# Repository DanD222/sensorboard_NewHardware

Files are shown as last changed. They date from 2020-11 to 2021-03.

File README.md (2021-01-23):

# sensorboard_NewHardware
Hardware for a new version of the OpenVario Sensorboard, stemming from discussion in these issues:

https://github.com/Openvario/sensord/issues/23

https://github.com/Openvario/sensord/issues/26

Features / comparison to the original OpenVario sensorboard:

   - Updated sensors and voltage regulators
   - A USB connector has been added in place of the 6pin I2C connector
   - There are footprints for three differential sensors (DLHR-L30G-E1BD-C-NAV8, 4515DO-DS3BK030DPL, AMS5915)
   - There are two I2C buses:
       - 1 - SDA0/SCL0 is the on-board sensor I2C bus, this goes to the ESP32
       - 2 - SDA1/SCL0 is the external I2C bus, going from the ESP32 to the 10pin IDC connector
       
     Both buses can be linked via solder jumpers on the bottom layer - this allows the sensors to be connected to the IDC connector directly without using the ESP32. This can be useful to get the new sensorboard integrated into the current OpenVario setup without having to implement the ESP32 first.
   - Pins for UART0 and UART1. The UART0 pin header has a 5V pin, so that it can connect for example directly to a HC-05 Bluetooth module (or a board with an RS232 interface)
   - An on-board 12V->5V PSU so that the sensorboard can be used stand-alone
   - Additional filtering - 5VD powers the digital stuff (USB, ESP32 voltage regulator); 5VC powers the sensitive stuff (sensor voltage regulators, audio amp)
   - The audio amp is a class AB TPA6211A1DRBR
   - There are pins around the audio amp so that a daughter board can be used in order to experiment with different amps
   - There are pins for selecting the source to the audio amp. This can be either the ESP32 for future use, or external input (to be backwards-compatible)
   - The OAT sensor has been moved to a 2.5mm jack
   - The audio output is on a 3.5mm stereo jack

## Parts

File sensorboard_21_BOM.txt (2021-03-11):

Partlist exported from /Users/dan/openvario/hpmax/sensorboard_21.sch at 8/3/21 23:23 PM

Part                  Value                          Device                            Package                        Description                                                                                                                                           4515DO-DS3BK030DPL_NO_SILK AMS-5915 ARROW_ELECTRONICS-PURCHASE-URL                              AVAILABILITY DESCRIPTION                                                                                                                   DIGIKEY-PURCHASE-URL                              DLHR-L30G-E1BD-C-NAV8 HEIGHT  MANUFACTURER_NAME         MANUFACTURER_PART_NUMBER        MF                 MOUSER-PURCHASE-URL                              MOUSER_PART_NUMBER   MOUSER_PRICE-STOCK                                                                                                             MP               MPN        OC_FARNELL OC_NEWARK PACKAGE                     POPULARITY PRICE PURCHASE-URL                                                  SPICEPREFIX
12V_IN                22-23-2021                     22-23-2021                        22-23-2021                     .100" (2.54mm) Center Header - 2 Pin                                                                                                                                                                                                                                                                                                                                                                                                                                                                                                       MOLEX                                                                                                                                                                                                                                    22-23-2021 1462926    25C3832                               40                                                                                        
AUD_DAUGHTER-B_OUT                                   PINHD-1X2                         1X02                           PIN HEADER                                                                                                                                                                                                                                                                                                                                                                                                                                                                                                                                                                                                                                                                                                                                                                                                                                      98                                                                                        
AUD_IN                                               PINHD-1X3                         1X03                           PIN HEADER                                                                                                                                                                                                                                                                                                                                                                                                                                                                                                                                                                                                                                                                                                                                                                                                                                      92                                                                                        
C1                    100nF                          C-EUC0603                         C0603                          CAPACITOR, European symbol                                                                                                                                                                                                                                                                                                                                                                                                                                                                                                                                                                                                                                                                                                                                                                                                                      73                                                                             C          
C2                    100nF                          C-EUC0603                         C0603                          CAPACITOR, European symbol                                                                                                                                                                                                                                                                                                                                                                                                                                                                                                                                                                                                                                                                                                                                                                                                                      73                                                                             C          
C3                    100nF                          C-EUC0805                         C0805                          CAPACITOR, European symbol                                                                                                                                                                                                                                                                                                                                                                                                                                                                                                                                                                                                                                                                                                                                                                                                                      88                                                                             C          
C4                    10uF                           C-EUC0805                         C0805                          CAPACITOR, European symbol                                                                                                                                                                                                                                                                                                                                                                                                                                                                                                                                                                                                                                                                                                                                                                                                                      88                                                                             C          
C5                    10uF                           C-EUC0805                         C0805                          CAPACITOR, European symbol                                                                                                                                                                                                                                                                                                                                                                                                                                                                                                                                                                                                                                                                                                                                                                                                                      88                                                                             C          
C6                    1uF                            C-EUC0805                         C0805                          CAPACITOR, European symbol                                                                                                                                                                                                                                                                                                                                                                                                                                                                                                                                                                                                                                                                                                                                                                                                                      88                                                                             C          
C7                    1uF                            C-EUC0805                         C0805                          CAPACITOR, European symbol                                                                                                                                                                                                                                                                                                                                                                                                                                                                                                                                                                                                                                                                                                                                                                                                                      88                                                                             C          
C8                    10uF                           C-EUC0805                         C0805                          CAPACITOR, European symbol                                                                                                                                                                                                                                                                                                                                                                                                                                                                                                                                                                                                                                                                                                                                                                                                                      88                                                                             C          
C9                    1uF                            C-EUC0805                         C0805                          CAPACITOR, European symbol                                                                                                                                                                                                                                                                                                                                                                                                                                                                                                                                                                                                                                                                                                                                                                                                                      88                                                                             C          
C10                   10uF                           C-EUC0805                         C0805                          CAPACITOR, European symbol                                                                                                                                                                                                                                                                                                                                                                                                                                                                                                                                                                                                                                                                                                                                                                                                                      88                                                                             C          
C11                   100nF                          C-EUC0805                         C0805                          CAPACITOR, European symbol                                                                                                                                                                                                                                                                                                                                                                                                                                                                                                                                                                                                                                                                                                                                                                                                                      88                                                                             C          
C12                   10uF                           C-EUC0805                         C0805                          CAPACITOR, European symbol                                                                                                                                                                                                                                                                                                                                                                                                                                                                                                                                                                                                                                                                                                                                                                                                                      88                                                                             C          
C13                   100nF                          C-EUC0805                         C0805                          CAPACITOR, European symbol                                                                                                                                                                                                                                                                                                                                                                                                                                                                                                                                                                                                                                                                                                                                                                                                                      88                                                                             C          
C14                   1uF                            C-EUC0805                         C0805                          CAPACITOR, European symbol                                                                                                                                                                                                                                                                                                                                                                                                                                                                                                                                                                                                                                                                                                                                                                                                                      88                                                                             C          
C15                   1uF                            C-EUC0805                         C0805                          CAPACITOR, European symbol                                                                                                                                                                                                                                                                                                                                                                                                                                                                                                                                                                                                                                                                                                                                                                                                                      88                                                                             C          
C16                   100nF                          C-EUC0805                         C0805                          CAPACITOR, European symbol                                                                                                                                                                                                                                                                                                                                                                                                                                                                                                                                                                                                                                                                                                                                                                                                                      88                                                                             C          
C17                   22uF/25V                       CL31A226KAHNNNE                   CAPC3216X180N                  SAMSUNG ELECTRO-MECHANICS - CL31A226KAHNNNE - CAP, 22UF, 25V, MLCC, 1206                                                                                                                                                                                           SAMSUNG ELECTRO-MECHANICS - CL31A226KAHNNNE - CAP, 22UF, 25V, MLCC, 1206                                                                                                                              1.8mm   Samsung Electro-Mechanics CL31A226KAHNNNE                                                                                     N/A                  https://www.mouser.com/Search/Refine.aspx?Keyword=N%2FA                                                                                                                                                                                                                                               
C18                   22uF/25V                       CL31A226KAHNNNE                   CAPC3216X180N                  SAMSUNG ELECTRO-MECHANICS - CL31A226KAHNNNE - CAP, 22UF, 25V, MLCC, 1206                                                                                                                                                                                           SAMSUNG ELECTRO-MECHANICS - CL31A226KAHNNNE - CAP, 22UF, 25V, MLCC, 1206                                                                                                                              1.8mm   Samsung Electro-Mechanics CL31A226KAHNNNE                                                                                     N/A                  https://www.mouser.com/Search/Refine.aspx?Keyword=N%2FA                                                                                                                                                                                                                                               
C19                   1uF                            C-EUC0805                         C0805                          CAPACITOR, European symbol                                                                                                                                                                                                                                                                                                                                                                                                                                                                                                                                                                                                                                                                                                                                                                                                                      88                                                                             C          
C20                   47pF                           C-EUC0805                         C0805                          CAPACITOR, European symbol                                                                                                                                                                                                                                                                                                                                                                                                                                                                                                                                                                                                                                                                                                                                                                                                                      88                                                                             C          
C21                   22uF/25V                       CL31A226KAHNNNE                   CAPC3216X180N                  SAMSUNG ELECTRO-MECHANICS - CL31A226KAHNNNE - CAP, 22UF, 25V, MLCC, 1206                                                                                                                                                                                           SAMSUNG ELECTRO-MECHANICS - CL31A226KAHNNNE - CAP, 22UF, 25V, MLCC, 1206                                                                                                                              1.8mm   Samsung Electro-Mechanics CL31A226KAHNNNE                                                                                     N/A                  https://www.mouser.com/Search/Refine.aspx?Keyword=N%2FA                                                                                                                                                                                                                                               
C22                   22uF/25V                       CL31A226KAHNNNE                   CAPC3216X180N                  SAMSUNG ELECTRO-MECHANICS - CL31A226KAHNNNE - CAP, 22UF, 25V, MLCC, 1206                                                                                                                                                                                           SAMSUNG ELECTRO-MECHANICS - CL31A226KAHNNNE - CAP, 22UF, 25V, MLCC, 1206                                                                                                                              1.8mm   Samsung Electro-Mechanics CL31A226KAHNNNE                                                                                     N/A                  https://www.mouser.com/Search/Refine.aspx?Keyword=N%2FA                                                                                                                                                                                                                                               
C23                   470pF                          C-EUC0805                         C0805                          CAPACITOR, European symbol                                                                                                                                                                                                                                                                                                                                                                                                                                                                                                                                                                                                                                                                                                                                                                                                                      88                                                                             C          
C24                   470pF                          C-EUC0805                         C0805                          CAPACITOR, European symbol                                                                                                                                                                                                                                                                                                                                                                                                                                                                                                                                                                                                                                                                                                                                                                                                                      88                                                                             C          
C25                   220nF                          C-EUC1206                         C1206                          CAPACITOR, European symbol                                                                                                                                                                                                                                                                                                                                                                                                                                                                                                                                                                                                                                                                                                                                                                                                                      54                                                                             C
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

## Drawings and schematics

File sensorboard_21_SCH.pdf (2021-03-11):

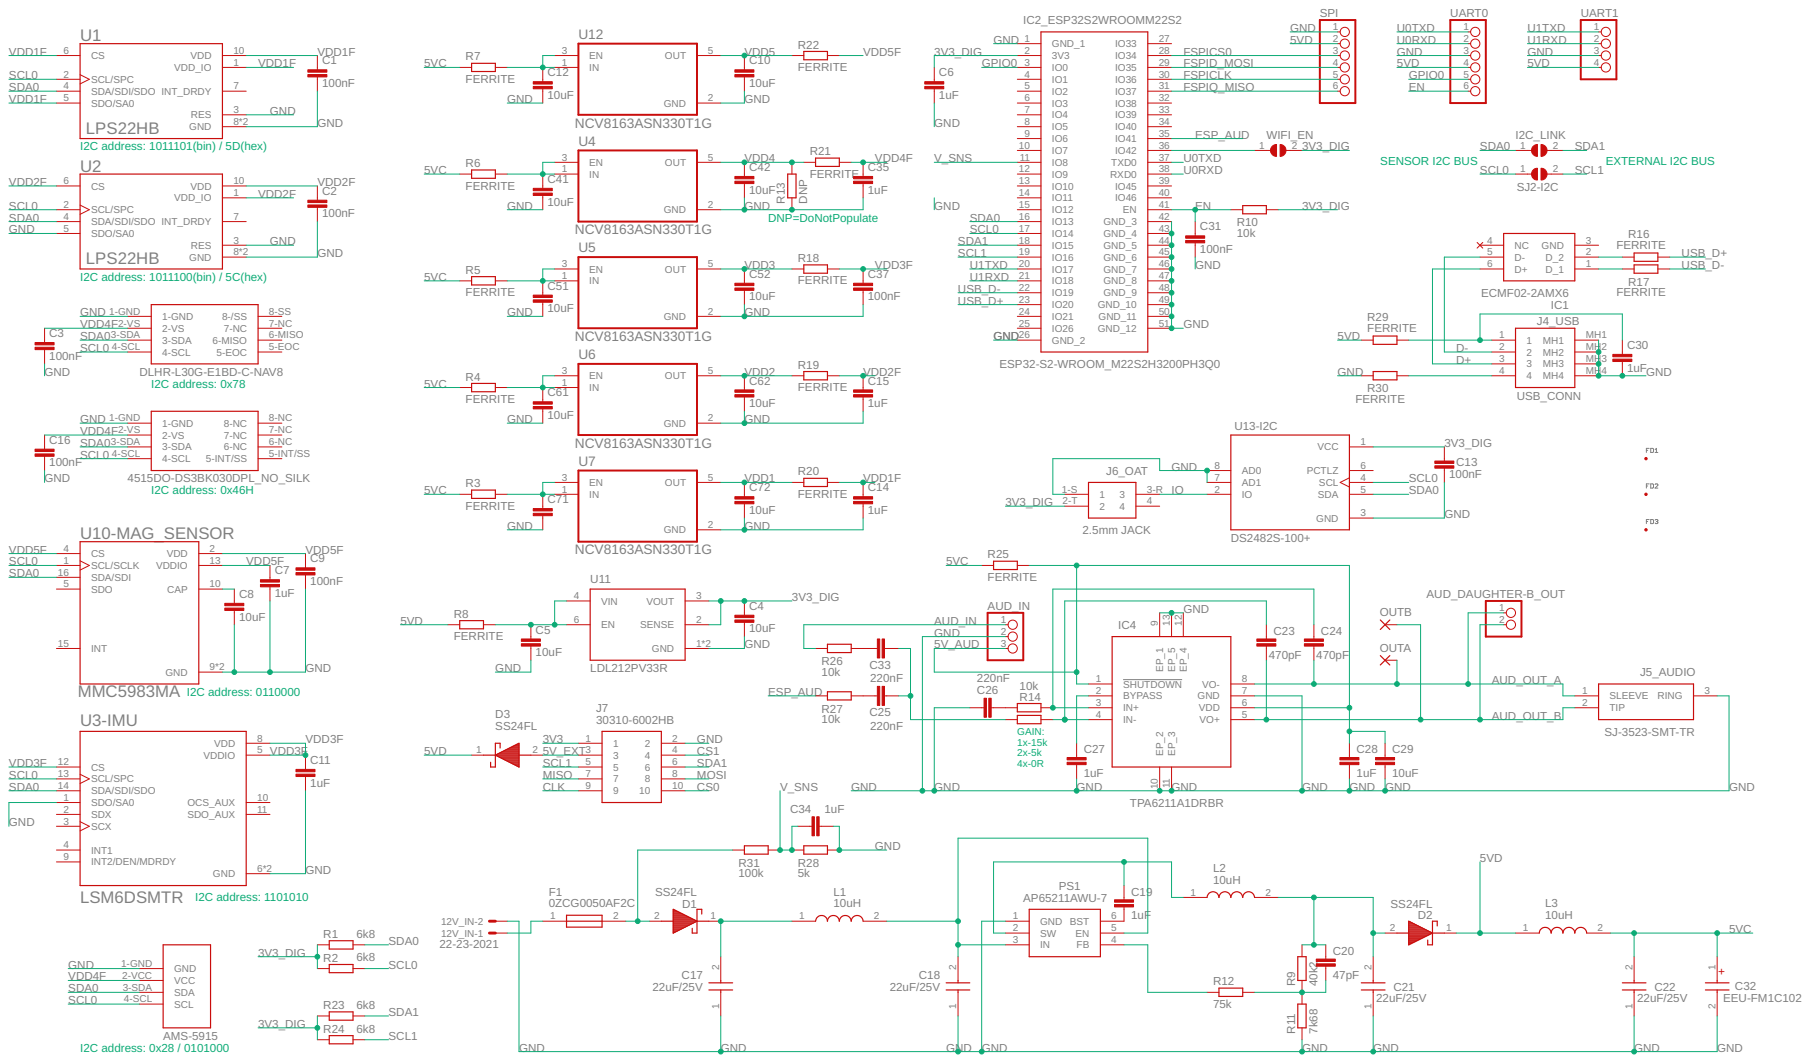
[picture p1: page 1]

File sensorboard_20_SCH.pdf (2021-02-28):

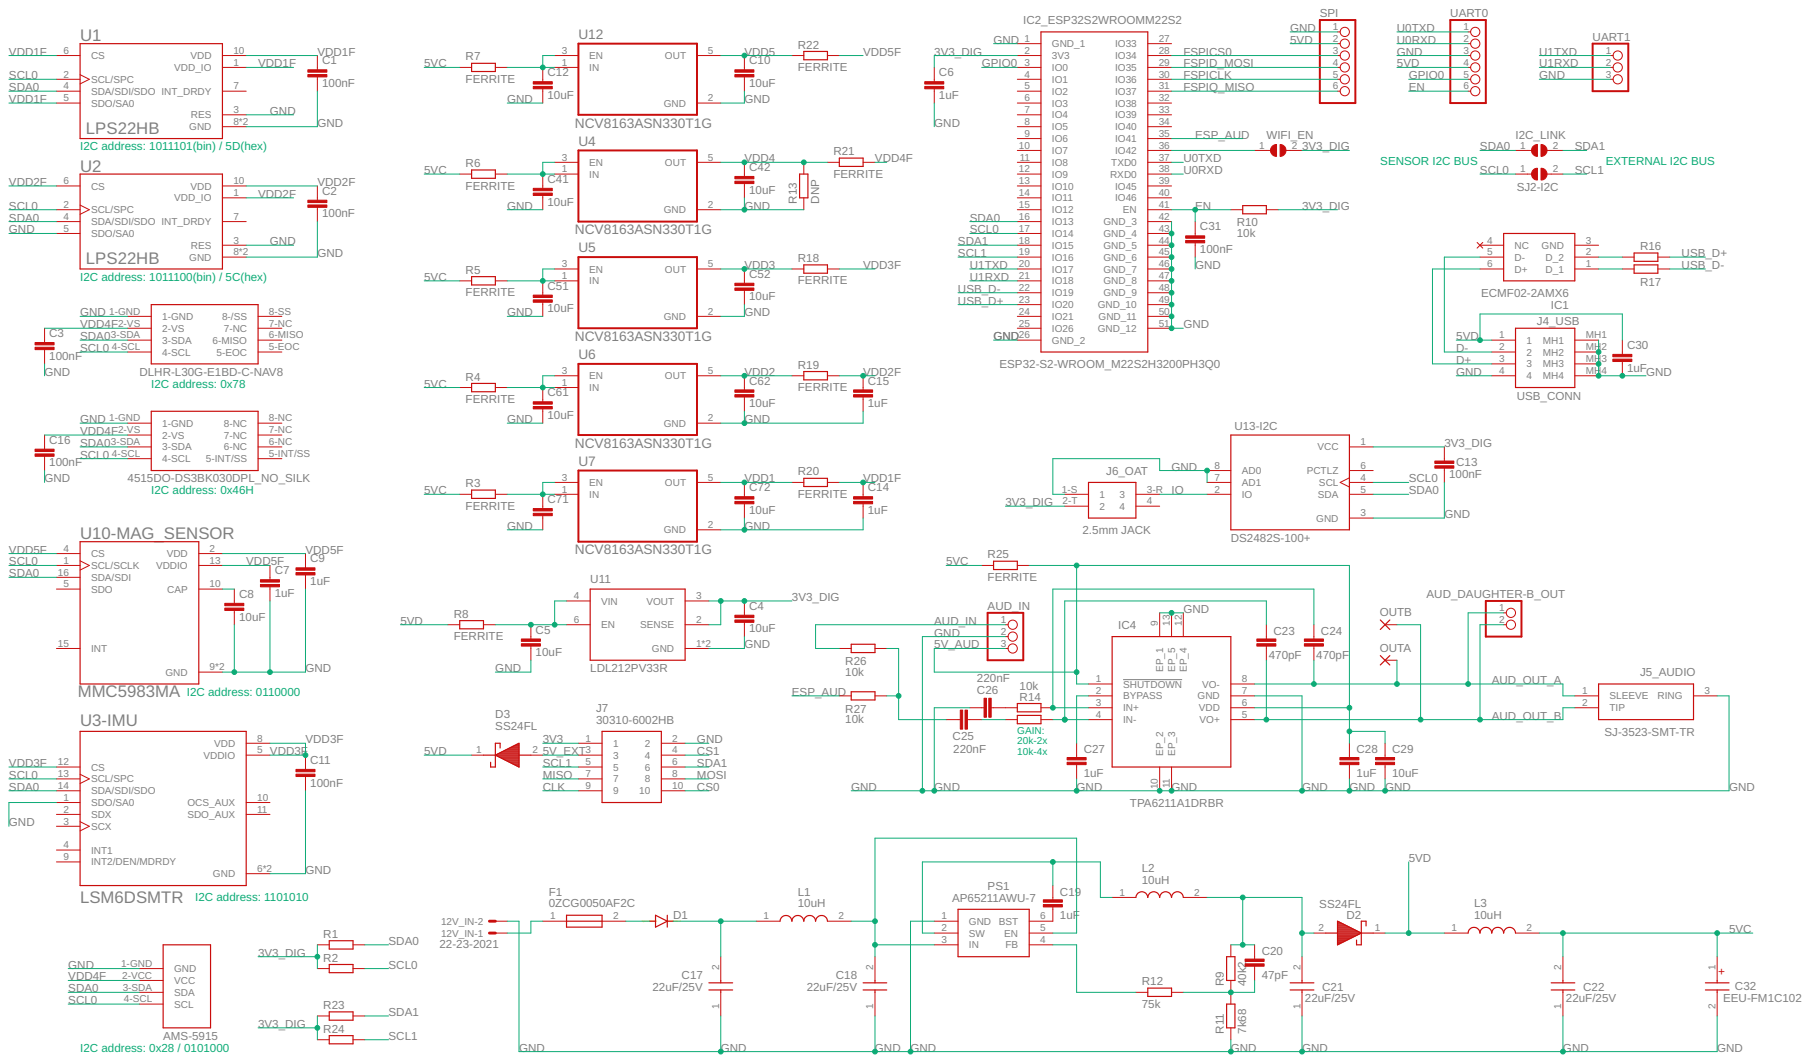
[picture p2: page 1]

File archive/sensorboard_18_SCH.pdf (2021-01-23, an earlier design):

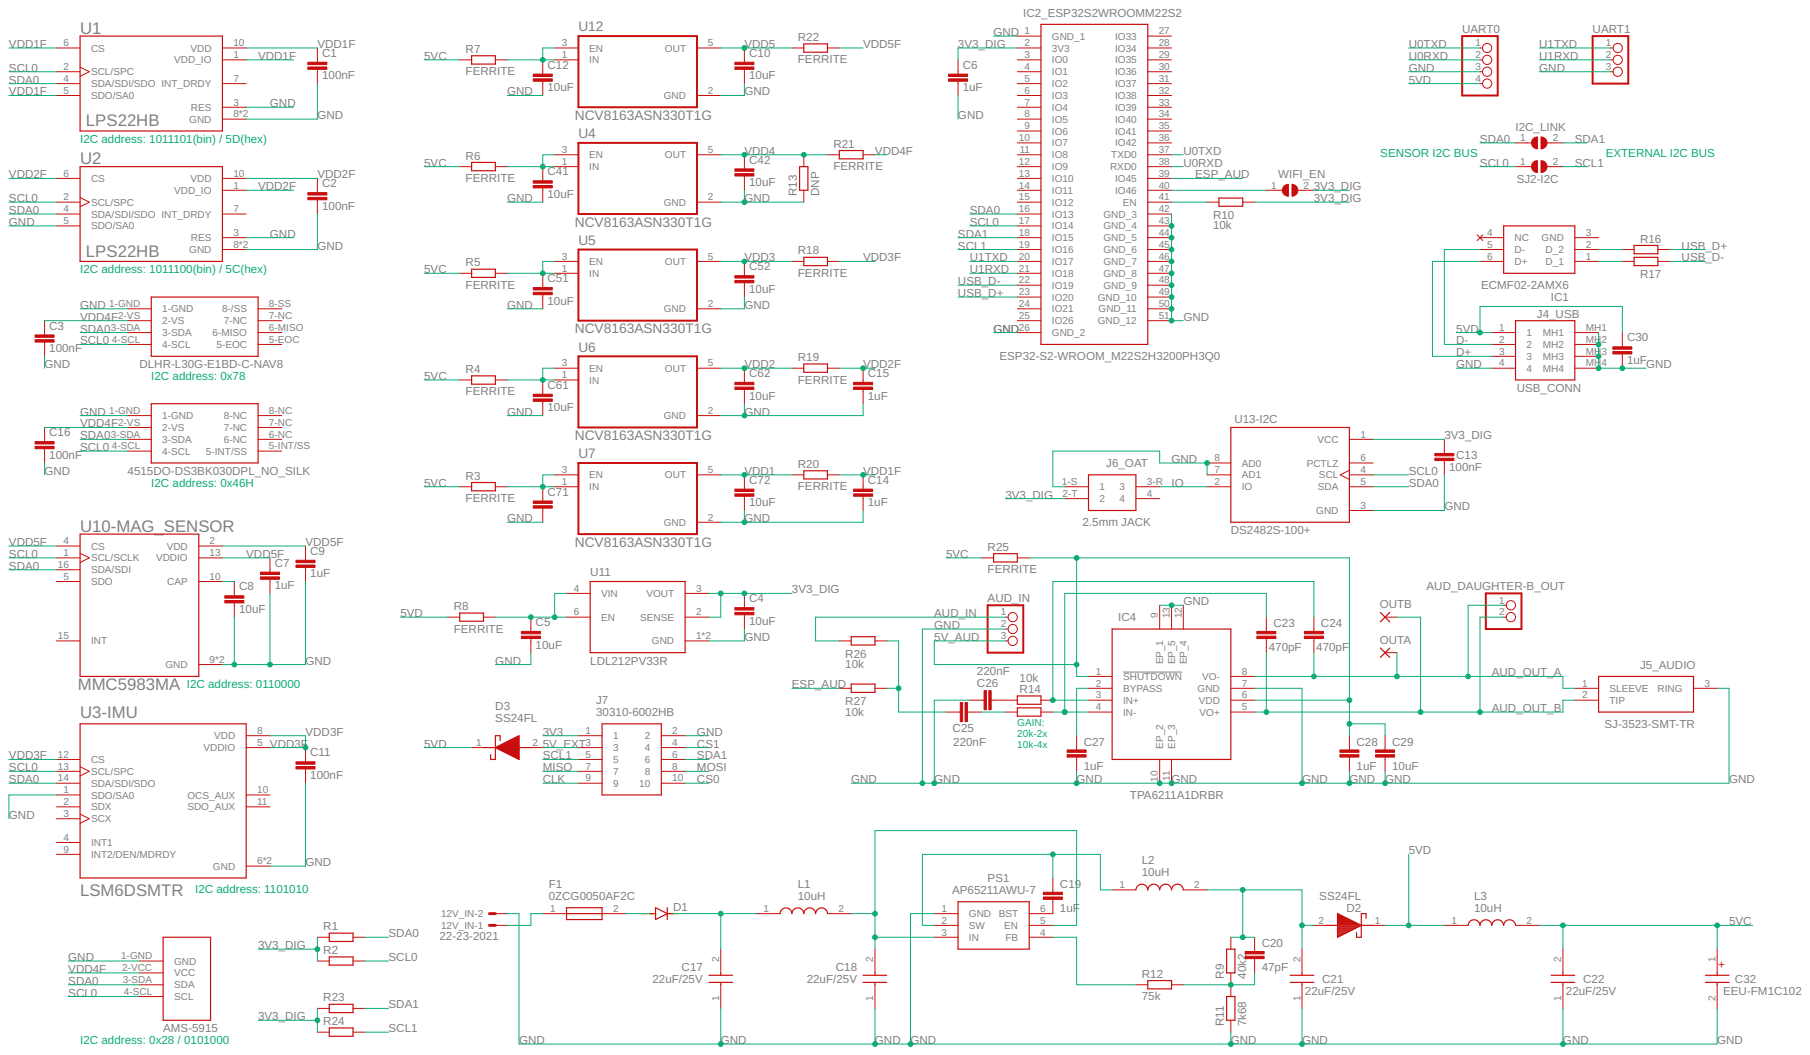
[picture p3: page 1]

GND GND GND

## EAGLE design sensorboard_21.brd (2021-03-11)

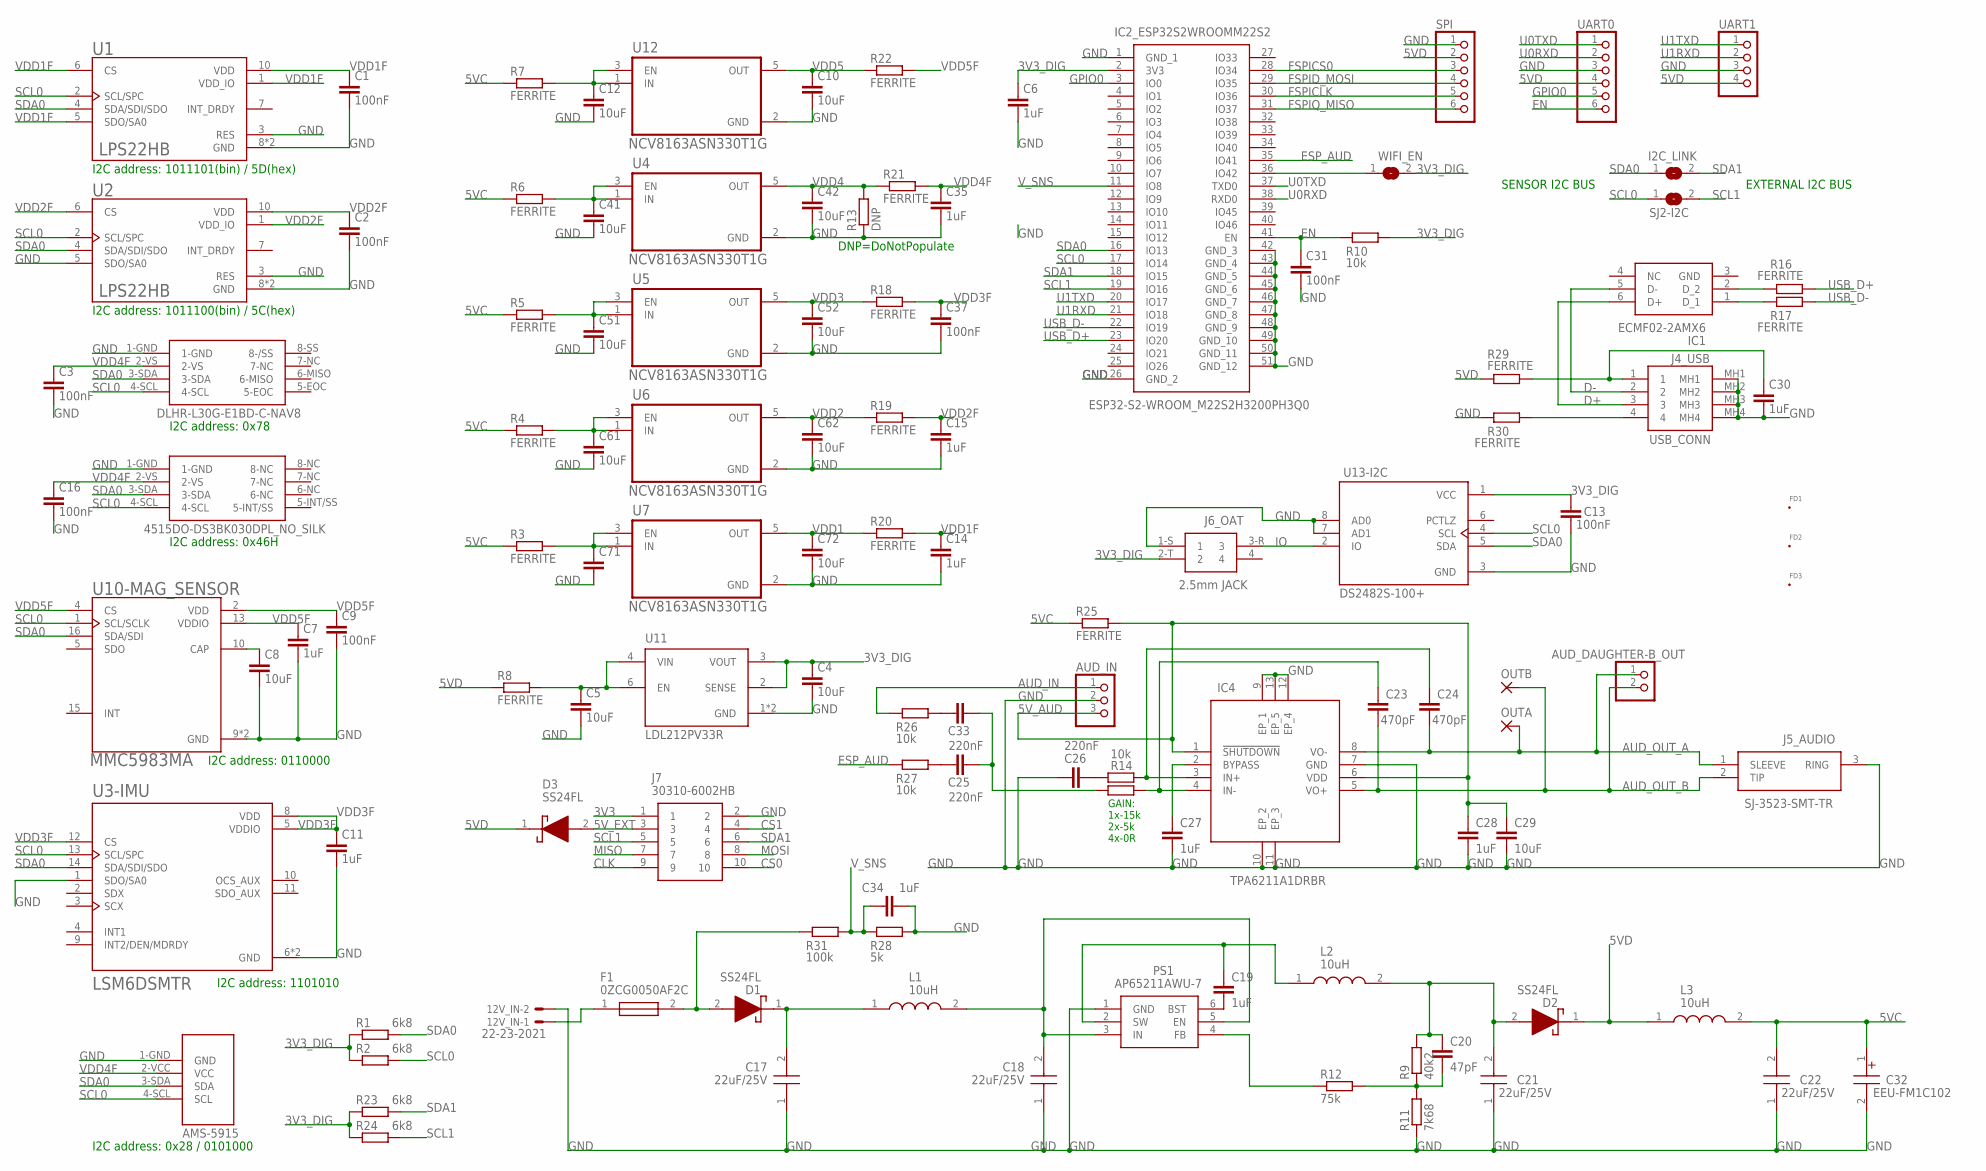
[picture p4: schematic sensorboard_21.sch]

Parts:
12V_IN: 22-23-2021
AUD_DAUGHTER-B_OUT: PINHD-1X2; 1X02
AUD_IN: PINHD-1X3; 1X03
C1, C2, C31: 100nF; C0603
C3, C9, C13, C16, C37: 100nF; C0805
C4, C5, C8, C10, C12, C41, C42, C51, C52, C61, C62, C72: 10uF; C0805
C6, C7, C11, C14, C15, C19, C30, C34, C35: 1uF; C0805
C17, C18, C21, C22: 22uF/25V; CAPC3216X180N
C20: 47pF; C0805
C23, C24: 470pF; C0805
C25, C26, C33: 220nF; C1206
C27, C28: 1uF; C1206
C29: 10uF; C1206
C32: EEU-FM1C102; CAPPRD500W65D1000H2200
C71: C-EUC0805; C0805
D1, D2, D3: SS24FL; SODFL3617X108N
DLHR-L30G-E1BD-C-NAV8: DLHR-L30G-E1BD-C-NAV8
F1: 0ZCG0050AF2C; FUSC4632X75N
FD1, FD2, FD3: FID_20MIL_P; FID_020_P
I2C_LINK: SJ
IC1: ECMF02-2AMX6; SON50P150X170X55-6N
IC2_ESP32S2WROOMM22S2: ESP32-S2-WROOM_M22S2H3200PH3Q0; ESP32S2WROOMM22S2H3200PH3Q0
IC4: TPA6211A1DRBR; TPS7A8033DRBT
J4_USB: USB_CONN; 737250110BLF
J5_AUDIO: SJ-3523-SMT-TR; SJ3523SMTTR
J6_OAT: 2.5mm JACK; SJ-2523-SMT-TR
J7: 30310-6002HB; SHDR10W64P254_2X5_2030X878X930
L1, L2, L3: 10uH; FDSD0420WH150MP3
OUTA: SMD2_SMALLSMALL; SMD2_SMALL
OUTB: SMD2_SMALLSMALL; SMD2_SMALL
PS1: AP65211AWU-7; SOT95P280X90-6N
R1, R2, R23, R24: 6k8; R0805
R3, R4, R5, R6, R7, R8, R16, R17, R18, R19, R20, R21, R22, R25, R29, R30: FERRITE; R0805
R9: 40k2; R0805
R10, R14, R26, R27: 10k; R0805
R11: 7k68; R0805
R12: 75k; R0805
R13: DNP; R0805
R15: R-EU_R0805; R0805
R28: 5k; R0805
R31: 100k; R0805
SJ2-I2C: SJ
SPI: PINHD-1X6; 1X06
U1, U2: LPS22HB; LGA10R50P2X3_200X200X80
U3-IMU: LSM6DSMTR; PQFN50P300X250X86-14N
U4, U5, U6, U7, U12: NCV8163ASN330T1G; SOP95P275X110-5N
U10-MAG_SENSOR: MMC5983MA; LGA16R50P4X4_330X330X100
U11: LDL212PV33R; SON50P200X200X80-7N
U13-I2C: DS2482S-100+; SOIC127P600X175-8N
U$1: AMS-5915
U$4: 4515DO-DS3BK030DPL_NO_SILKNO_SILK; 4515DO-DS3BK030DPL_NO_SILK
UART0: PINHD-1X6; 1X06
UART1: PINHD-1X4; 1X04
WIFI_EN: SJ

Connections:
3V3: J7.1
3V3_DIG: C4.1, C6.1, C13.1, IC2_ESP32S2WROOMM22S2.2 (3V3), J6_OAT.2-T (2), R1.1, R2.1, R10.2, R23.1, R24.1, U11.2 (SENSE), U11.3 (VOUT), U13-I2C.1 (VCC), WIFI_EN.2
5VC: C22.2, C32.1 (+), L3.2, R3.1, R4.1, R5.1, R6.1, R7.1, R25.1
5VD: D2.1 (K), D3.1 (K), L3.1, R8.1, R29.1, SPI.2, UART0.4, UART1.4
5V_AUD: AUD_IN.3, C28.1, C29.1, IC4.1 (!SHUTDOWN), IC4.6 (VDD), R25.2
5V_EXT: D3.2 (A), J7.3
AUD_IN: AUD_IN.1, R26.1
AUD_OUT_A: AUD_DAUGHTER-B_OUT.1, C24.2, IC4.8 (VO-), J5_AUDIO.1 (SLEEVE), OUTA.1
AUD_OUT_B: AUD_DAUGHTER-B_OUT.2, C23.2, IC4.5 (VO+), J5_AUDIO.2 (TIP), OUTB.1
CLK: J7.9
CS0: J7.10
CS1: J7.4
D+: IC1.6 (D+), J4_USB.3
D-: IC1.5 (D-), J4_USB.2
EN: C31.1, IC2_ESP32S2WROOMM22S2.41 (EN), R10.1, UART0.6
ESP_AUD: IC2_ESP32S2WROOMM22S2.35 (IO41), R27.1
FSPICLK: IC2_ESP32S2WROOMM22S2.30 (IO36), SPI.5
FSPICS0: IC2_ESP32S2WROOMM22S2.28 (IO34), SPI.3
FSPID_MOSI: IC2_ESP32S2WROOMM22S2.29 (IO35), SPI.4
FSPIQ_MISO: IC2_ESP32S2WROOMM22S2.31 (IO37), SPI.6
GND: 12V_IN.2, AUD_IN.2, C1.2, C2.2, C3.2, C4.2, C5.2, C6.2, C7.2, C8.2, C9.2, C10.2, C11.2, C12.2, C13.2, C14.2, C15.2, C16.2, C17.1, C18.1, C21.1, C22.1, C26.1, C27.2, C28.2, C29.2, C30.2, C31.2, C32.2 (-), C34.2, C35.2, C37.2, C41.2, C42.2, C51.2, C52.2, C61.2, C62.2, C71.2, C72.2, DLHR-L30G-E1BD-C-NAV8.1-GND, IC1.3 (GND), IC2_ESP32S2WROOMM22S2.1 (GND_1), IC2_ESP32S2WROOMM22S2.26 (GND_2), IC2_ESP32S2WROOMM22S2.42 (GND_3), IC2_ESP32S2WROOMM22S2.43 (GND_4), IC2_ESP32S2WROOMM22S2.44 (GND_5), IC2_ESP32S2WROOMM22S2.45 (GND_6), IC2_ESP32S2WROOMM22S2.46 (GND_7), IC2_ESP32S2WROOMM22S2.47 (GND_8), IC2_ESP32S2WROOMM22S2.48 (GND_9), IC2_ESP32S2WROOMM22S2.49 (GND_10), IC2_ESP32S2WROOMM22S2.50 (GND_11), IC2_ESP32S2WROOMM22S2.51 (GND_12), IC4.7 (GND), IC4.9 (EP_1), IC4.10 (EP_2), IC4.11 (EP_3), IC4.12 (EP_4), IC4.13 (EP_5), J4_USB.MH1, J4_USB.MH2, J4_USB.MH3, J4_USB.MH4, J5_AUDIO.3 (RING), J6_OAT.1-S (1), J7.2, PS1.1 (GND), R11.1, R13.1, R28.2, R30.1, SPI.1, U1.3 (RES), U1.8 (GND), U1.9 (GND), U2.3 (RES), U2.5 (SDO/SA0), U2.8 (GND), U2.9 (GND), U3-IMU.1 (SDO/SA0), U3-IMU.6 (GND), U3-IMU.7 (GND), U4.2 (GND), U5.2 (GND), U6.2 (GND), U7.2 (GND), U10-MAG_SENSOR.9 (GND), U10-MAG_SENSOR.11 (GND), U11.1 (GND), U11.7 (GND), U12.2 (GND), U13-I2C.3 (GND), U13-I2C.7 (AD1), U13-I2C.8 (AD0), U$1.1-GND (GND), U$4.1-GND, UART0.3, UART1.3
GPIO0: IC2_ESP32S2WROOMM22S2.3 (IO0), UART0.5
IO: J6_OAT.3-R (3), U13-I2C.2 (IO)
MISO: J7.7
MOSI: J7.8
unnamed: C8.1, U10-MAG_SENSOR.10 (CAP)
unnamed: C30.1, J4_USB.1, R29.2
unnamed: C23.1, IC4.4 (IN-), R15.2
unnamed: C17.2, D1.1 (K), L1.1
unnamed: C18.2, L1.2, PS1.3 (IN), PS1.5 (EN)
unnamed: C25.2, C33.2, R15.1
unnamed: C20.2, R9.1, R11.2, R12.2
unnamed: C19.1, L2.1, PS1.2 (SW)
unnamed: PS1.4 (FB), R12.1
unnamed: C19.2, PS1.6 (BST)
unnamed: C24.1, IC4.3 (IN+), R14.2
unnamed: C26.2, R14.1
unnamed: J4_USB.4, R30.2
unnamed: 12V_IN.1, F1.1
unnamed: IC2_ESP32S2WROOMM22S2.36 (IO42), WIFI_EN.1
unnamed: C27.1, IC4.2 (BYPASS)
unnamed: IC1.1 (D_1), R17.1
unnamed: IC1.2 (D_2), R16.1
unnamed: C25.1, R27.2
unnamed: C33.1, R26.2
unnamed: C20.1, C21.2, D2.2 (A), L2.2, R9.2
unnamed: D1.2 (A), F1.2, R31.1
SCL0: DLHR-L30G-E1BD-C-NAV8.4-SCL, IC2_ESP32S2WROOMM22S2.17 (IO14), R2.2, SJ2-I2C.1, U1.2 (SCL/SPC), U2.2 (SCL/SPC), U3-IMU.13 (SCL/SPC), U10-MAG_SENSOR.1 (SCL/SCLK), U13-I2C.4 (SCL), U$1.4-SCL (SCL), U$4.4-SCL
SCL1: IC2_ESP32S2WROOMM22S2.19 (IO16), J7.5, R24.2, SJ2-I2C.2
SDA0: DLHR-L30G-E1BD-C-NAV8.3-SDA, I2C_LINK.1, IC2_ESP32S2WROOMM22S2.16 (IO13), R1.2, U1.4 (SDA/SDI/SDO), U2.4 (SDA/SDI/SDO), U3-IMU.14 (SDA/SDI/SDO), U10-MAG_SENSOR.16 (SDA/SDI), U13-I2C.5 (SDA), U$1.3-SDA (SDA), U$4.3-SDA
SDA1: I2C_LINK.2, IC2_ESP32S2WROOMM22S2.18 (IO15), J7.6, R23.2
U0RXD: IC2_ESP32S2WROOMM22S2.38 (RXD0), UART0.2
U0TXD: IC2_ESP32S2WROOMM22S2.37 (TXD0), UART0.1
U1RXD: IC2_ESP32S2WROOMM22S2.21 (IO18), UART1.2
U1TXD: IC2_ESP32S2WROOMM22S2.20 (IO17), UART1.1
USB_D+: IC2_ESP32S2WROOMM22S2.23 (IO20), R16.2
USB_D-: IC2_ESP32S2WROOMM22S2.22 (IO19), R17.2
VDD1: C72.1, R20.1, U7.5 (OUT)
VDD1F: C1.1, C14.1, R20.2, U1.1 (VDD_IO), U1.5 (SDO/SA0), U1.6 (CS), U1.10 (VDD)
VDD1P: C71.1, R3.2, U7.1 (IN), U7.3 (EN)
VDD2: C62.1, R19.1, U6.5 (OUT)
VDD2F: C2.1, C15.1, R19.2, U2.1 (VDD_IO), U2.6 (CS), U2.10 (VDD)
VDD2P: C61.1, R4.2, U6.1 (IN), U6.3 (EN)
VDD3: C52.1, R18.1, U5.5 (OUT)
VDD3F: C11.1, C37.1, R18.2, U3-IMU.5 (VDDIO), U3-IMU.8 (VDD), U3-IMU.12 (CS)
VDD3P: C51.1, R5.2, U5.1 (IN), U5.3 (EN)
VDD4: C42.1, R13.2, R21.1, U4.5 (OUT)
VDD4F: C3.1, C16.1, C35.1, DLHR-L30G-E1BD-C-NAV8.2-VS, R21.2, U$1.2-VCC (VCC), U$4.2-VS
VDD4P: C41.1, R6.2, U4.1 (IN), U4.3 (EN)
VDD5: C10.1, R22.1, U12.5 (OUT)
VDD5F: C7.1, C9.1, R22.2, U10-MAG_SENSOR.2 (VDD), U10-MAG_SENSOR.4 (CS), U10-MAG_SENSOR.13 (VDDIO)
VDD5P: C12.1, R7.2, U12.1 (IN), U12.3 (EN)
VDD_DIGP: C5.1, R8.2, U11.4 (VIN), U11.6 (EN)
V_SNS: C34.1, IC2_ESP32S2WROOMM22S2.11 (IO8), R28.1, R31.2

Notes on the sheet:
SENSOR I2C BUS
EXTERNAL I2C BUS
GAIN: 1x-15k 2x-5k 4x-0R
I2C address: 1101010
I2C address: 0110000
I2C address: 1011101(bin) / 5D(hex)
I2C address: 1011100(bin) / 5C(hex)
I2C address: 0x78
I2C address: 0x46H
I2C address: 0x28 / 0101000
DNP=DoNotPopulate

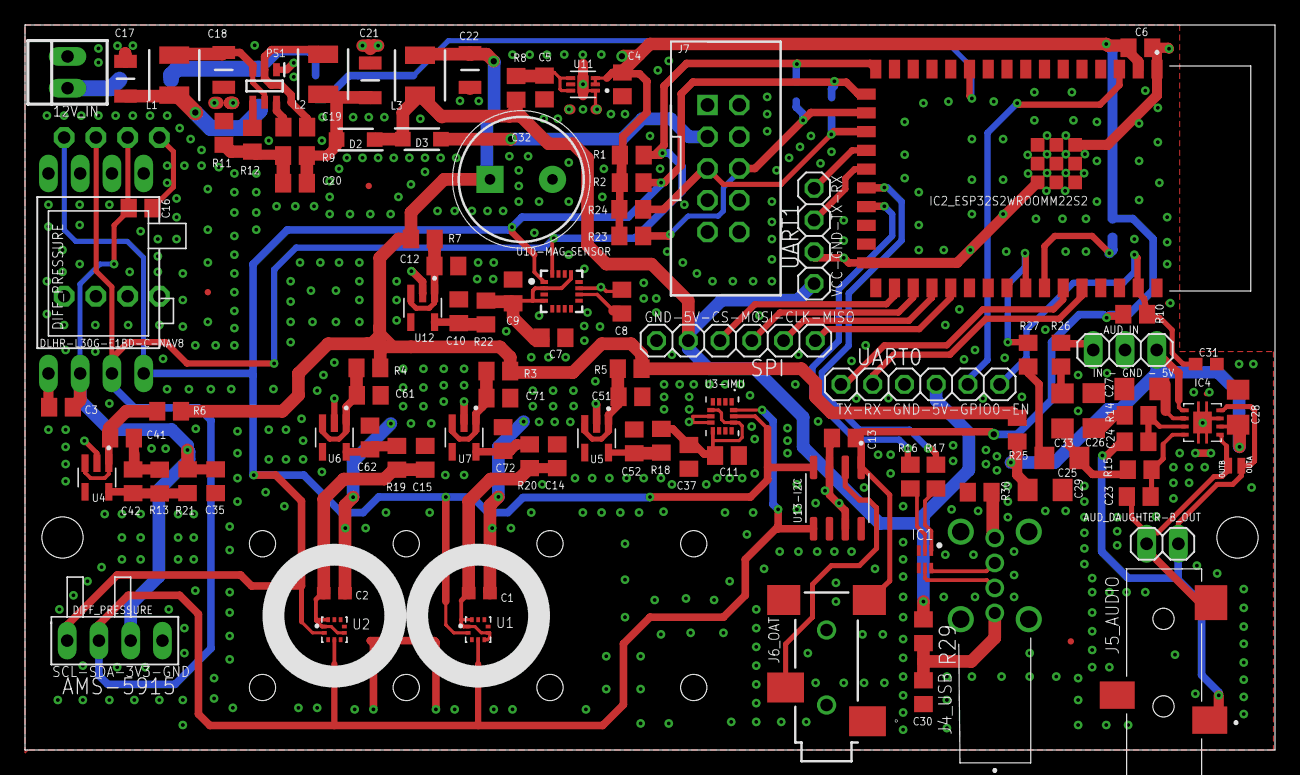
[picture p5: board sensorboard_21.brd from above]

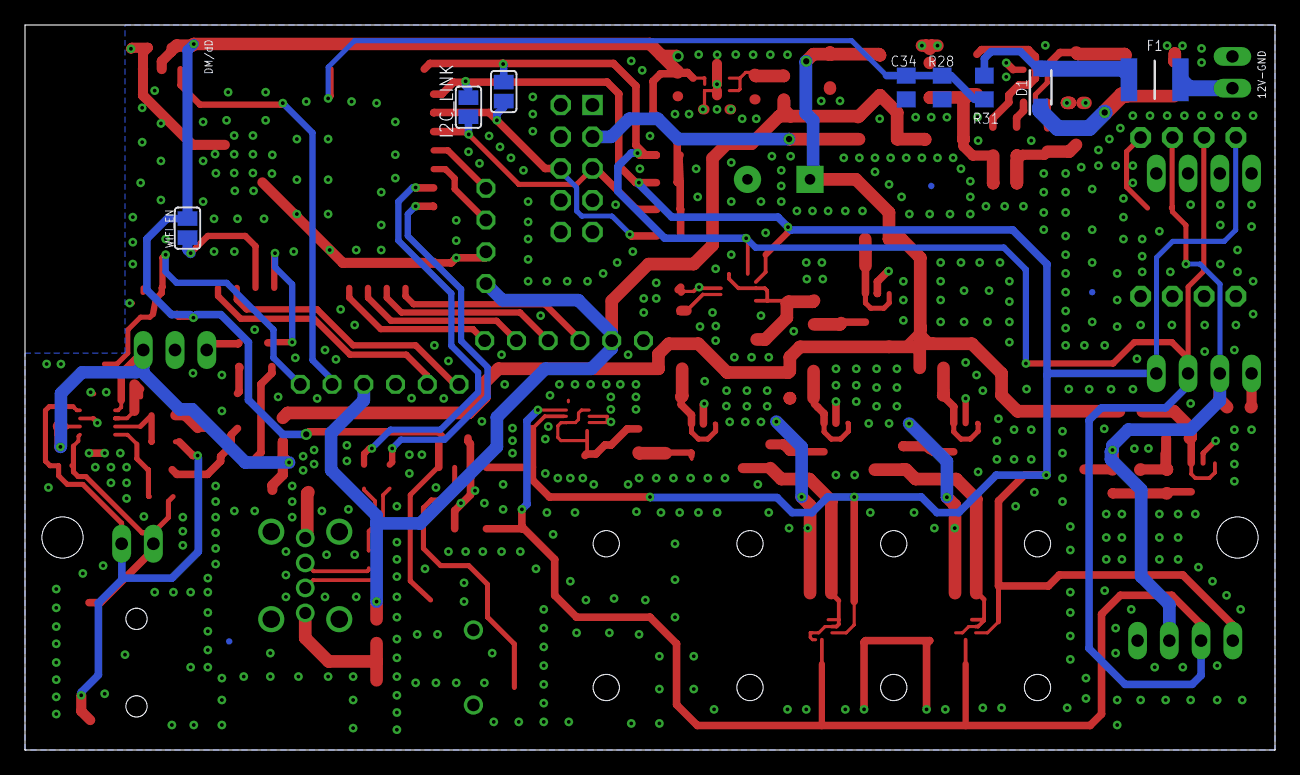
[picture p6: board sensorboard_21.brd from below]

Board: 2 copper layers, 100.0 x 58.0 mm, 118 parts (8 on the bottom side), 68 nets.

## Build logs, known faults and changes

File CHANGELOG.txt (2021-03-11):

v20
Added resistor divider to 12V input for battery voltage measurement on ESP32
Extended UART0 connector with VCC pin for HC-05 compatibility
Added capacitor to V_SNS pin

v20
Extended UART0 connector with EN, GPIO0 pins
Moved ESP_AUD, WIFI_EN to different ESP32 pins

v19
Added bypass capacitor to ESP32 EN pin

v18
Initial upload

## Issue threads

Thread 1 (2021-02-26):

ESP32 Reset

Tjeerdm, 2021-02-26:
The ESP32 reset line (EN) needs a capacitor to ground.
See https://www.espressif.com/sites/default/files/documentation/esp32-s2-wroom_esp32-s2-wroom-i_datasheet_en.pdf
Figure 6.

DanD222, 2021-02-26:
Thanks - fixed with 91d300ca74186b6ae7525fd264037ecde7ab9f06 and 641f369897ab1e9f81edeb3a6cbcbd9e41f9a276.

Closed 2021-02-26.

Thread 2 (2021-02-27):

Flash over USB/UART0 and EN/GPIO0

Tjeerdm, 2021-02-27:
Thanks for fixing #1.

According to https://www.esp32.com/viewtopic.php?t=18060 is advisable to provide connections to EN and GPIO0.
Especially for SW development.

I suggest extending the 4pin UART0 connector with these 2 signals.

Closed 2021-02-28.

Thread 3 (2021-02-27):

GPIO45 and GPIO46

Tjeerdm, 2021-02-27:
These are mode strapping inputs on power-up. GPIO45 changes the power supply voltage for the SPI ROM.
GPIO46 influences the boot mode.
I think they should not be used when not absolutely necessary.

Thats it for the time being :-) Have a nice weekend.

Tjeerd Mulder

DanD222, 2021-02-28:
Awesome, thakns for the input Tjeerd!

Closed 2021-02-28.

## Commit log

2020-11-25 upload v14 files
    [sensorboard_14.brd, sensorboard_14.sch, sensorboard_14_v7.brd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]
2021-01-23 upload v18 files
    [sensorboard_18.brd, sensorboard_18.sch, sensorboard_18_v7.brd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]
2021-02-26 Upload sensorboard_18_DS2_dD2 files
    - Enlarged via drill size
    - Added ESP_AUD pinhead
    Remove sensorboard_18_DS2_dD1 files
    [sensorboard_18_DS2_dD2.brd, sensorboard_18_DS2_dD2.sch]
2021-02-26 Upload sensorboard_19 files
    Increase via drill size
    Change USB common mode filter to larger part
    Add 6 pin header for SPI, 5V, GND
    Add ESP32 EN pin bypass capacitor
    Remove sensorboard_18 files
    [sensorboard_19.brd, sensorboard_19.sch, sensorboard_19v7.brd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]
2021-02-26 Upload sensorboard_18_DS2_dD2b files
    Remove sensorboard_18_DS2_dD2 files
    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
    [sensorboard_18_DS2_dD2b.brd, sensorboard_18_DS2_dD2b.sch]
2021-02-28 Upload v20 files
    Extend UART0 connector with EN, GPIO0 pins (Fixes #2)
    Move ESP_AUD, WIFI_EN to different ESP32 pins (Fixes #3)
    [sensorboard_20.brd, sensorboard_20.sch, sensorboard_20_DS2_dD.brd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]
2021-02-28 Archive v18 files
    Create archive directory with v18 files for use as assembly reference for previous board revision
    [sensorboard_18.brd, sensorboard_18.sch, sensorboard_18_DS2_dD2.brd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]
2021-03-07 Update v20 files
    Add files in Eagle 7 format
    [sensorboard_20_v7.brd, sensorboard_20_v7.sch]
2021-03-11 Upload v21 files
    Add resistor divider to 12V input for battery voltage measurement on ESP32
    Extend UART0 connector with VCC pin for HC-05 compatibility
    Add capacitor to summing resistors
    Add capacitor to V_SNS pin
    [sensorboard_20.brd, sensorboard_20.sch, sensorboard_20_v7.brd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]
